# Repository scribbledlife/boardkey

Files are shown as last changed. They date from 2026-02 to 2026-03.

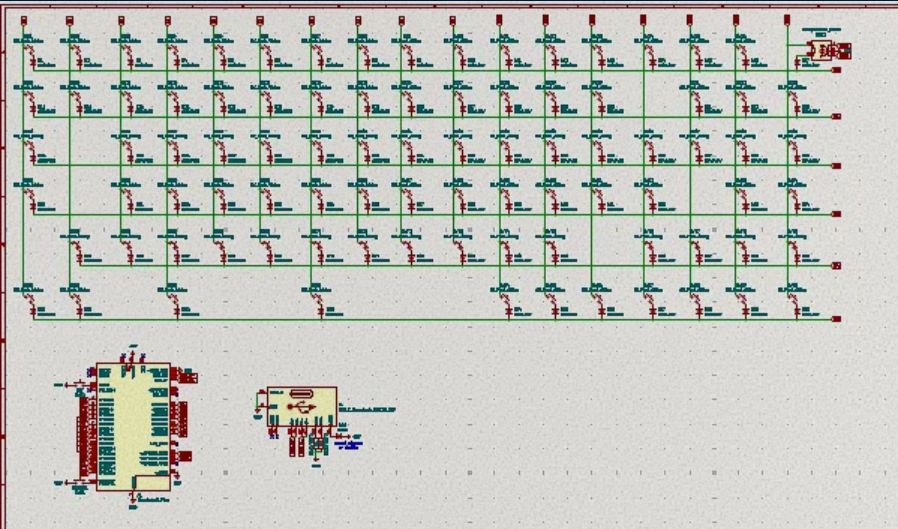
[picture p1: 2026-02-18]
images/boardkey_schematic.png

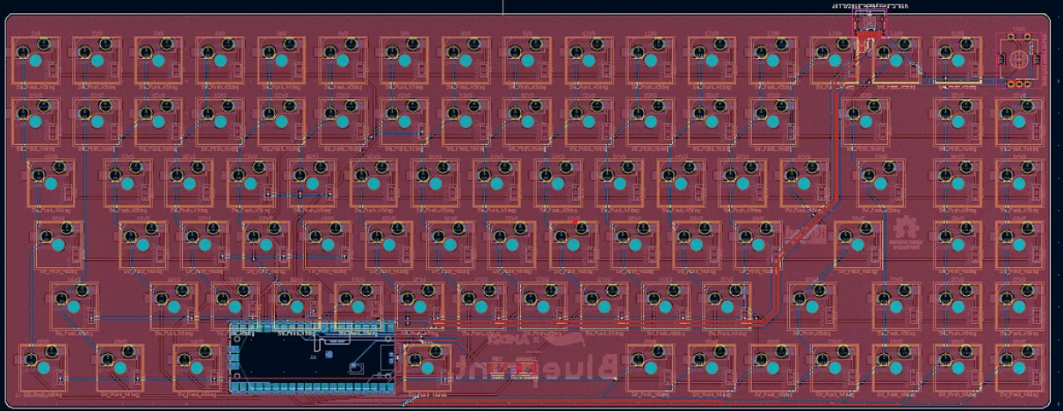
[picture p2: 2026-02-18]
images/boardkey_PCB.png

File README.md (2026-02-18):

# Boardkey

A custom 75% (84+5+1) mechanical keyboard powered by a Raspberry Pi Pico running KMK firmware.

## About

**boardkey** is a compact custom mechanical keyboard with the popular 75% layout extended with extra macro keys and a rotary encoder.

- **Layout**: 75% ANSI  
- **Total keys**: 90 (84 regular + 5 macro + 1 encoder switch)  
- **Microcontroller**: Raspberry Pi Pico  
- **Firmware**: KMK (Python-based, very flexible)

### Key breakdown
- 84 regular ANSI keys  
- 5 programmable macro/layer keys  
- 1 rotary encoder with integrated push switch



## Special Keys & Features

### Media Controls
- **Double tap F1** → Previous track  
- **Double tap F2** → Play / Pause  
- **Double tap F3** → Next track  

### Rotary Encoder
- **Turn left/right** → Volume Down / Volume Up  
- **Press + turn** → Brightness Down / Brightness Up  
- **Double press** → Mute / Unmute  

*(All of these are easily customizable in the `kb.py` / `main.py` KMK keymap file.)*

## Build details (optional sections you can expand)

- Case: 3D Printed, and looks like the following -





- Plate: Looks like this



- Switches: Gateron Milky Yellows
- Keycaps: PBT Keycaps
- Stabilizers: 2u and 6.25u Stabilizers
- PCB:



## Firmware

Firmware is written in CircuitPython using the excellent [KMK](https://github.com/KMKfw/kmk_firmware) framework.

Main features currently implemented:
- Layer switching
- Media keys via tap dance
- Rotary encoder volume & brightness control
- Macro keys (fully programmable)

To flash / edit:
1. Put the Pico into bootloader mode
2. Drag the KMK CircuitPython UF2 onto it
3. Edit `kb.py` and/or `keymaps/default.py`
4. Save → it auto-reloads

## Gallery

For more images, please go to the images folder, and if you want to see the materials, you can go to 

## Thanks / Inspiration

- Huge shoutout to the KMK community
- Linus Tech Tips
- Hack Club Community for the inspiration and help

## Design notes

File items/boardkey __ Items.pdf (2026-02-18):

Qty | Item/Name | Cost (CAD) | URL
89 | Gateron Milky Yellow Switches | $29.73 | Gateron Mily Yellow (https://www.aliexpress.com/item/1005008397216226.html?curPageLogUid=QEhXruD5pt11)
89 | Hotswappable Sockets | $10.02 | Kailhi Hot swappable Sockets (https://www.aliexpress.com/item/1005007639688349.html?mp=1)
90 | 1N4148W SOD-123 Diode | $1.59 | 1N4148W SOD-123 Diode (https://www.aliexpress.com/item/1005007536859190.html?curPageLogUid=dW8W7jVtVMJh)
1 | Rotary Encoder with switch | $1.59 | EC11 Rotary Encoder Code Switch (https://www.aliexpress.com/p/tesla-landing/index.html?scenario=c_ppc_item_bridge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)
3 | 2u Mx Stabilizer | $1.59 | 2u & 6.25U Stabilizer (https://www.aliexpress.com/item/1005004229140548.html?curPageLogUid=2GU49JZQrbhk)
1 | 6.25u Mx Stabilizer | $0 | 2u & 6.25U Stabilizer (https://www.aliexpress.com/item/1005004229140548.html?curPageLogUid=2GU49JZQrbhk)
1 | Keycap Set | $21.32 | PBT Keycaps (https://www.aliexpress.com/item/1005007051744953.html?curPageLogUid=0L05RmxX3qka)
1 | Raspberry Pi Pico (RP2350) | $10.68 | Raspberry Pi Pico RP2350 (https://www.aliexpress.com/item/1005007668131710.html?curPageLogUid=Zf9U3tLoK9uZ)
1 | USB C Socket | $1.38 | USB C Socket SMD (https://www.aliexpress.com/item/1005010588483093.html?curPageLogUid=UxecCxnBFgil)
2 | 5.1k 0402 SMD resistor | $2.07 | 5.1k 0402 SMD resistor (https://www.aliexpress.com/item/1005010725139976.html?curPageLogUid=Wq3j38MQqEIR)
4 | M2 Screw (13.9mm Max) | $1.59 | M2 Screw (12 mm) (https://www.aliexpress.com/item/32969042589.html?curPageLogUid=ekUhYhjyRFyN)
4 | M2 Heatset Female Socket | $1.59 | M2 Heatset Insert (OD3.2mm, 3mm deep) (https://www.aliexpress.com/item/1005010362011631.html?curPageLogUid=dGmJEGkHirNR)
1 | PCB | $29.84 | www.jlcpcb.com
1 | 3D Printed Case | ? | Printing Legion

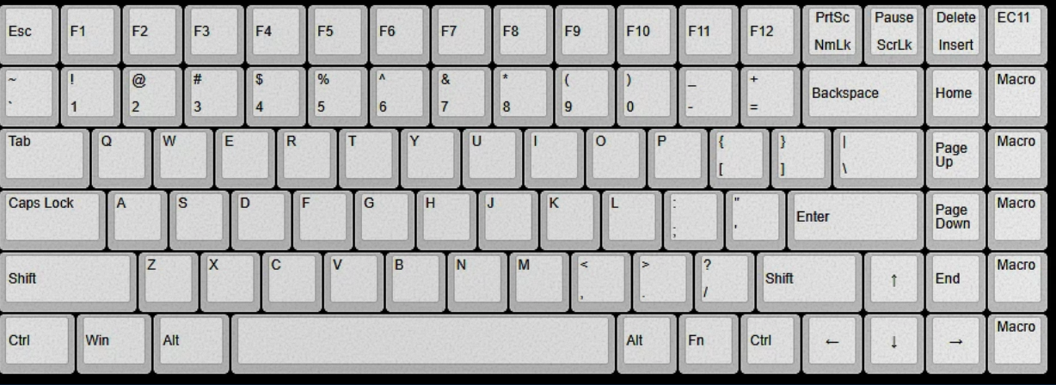
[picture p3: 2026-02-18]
images/boardkey_keyboard_layout.png

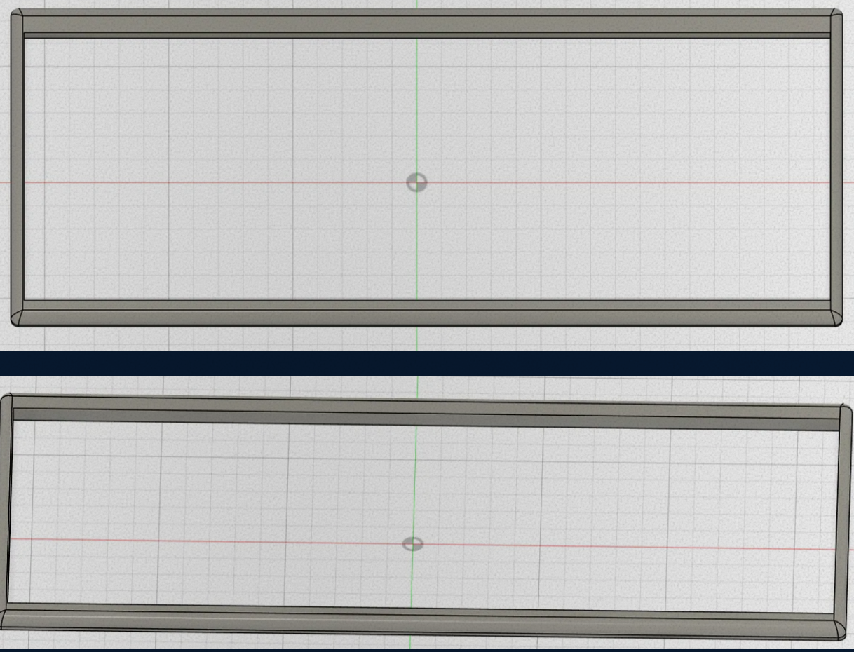
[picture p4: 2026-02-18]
images/boardkey_topcase.png

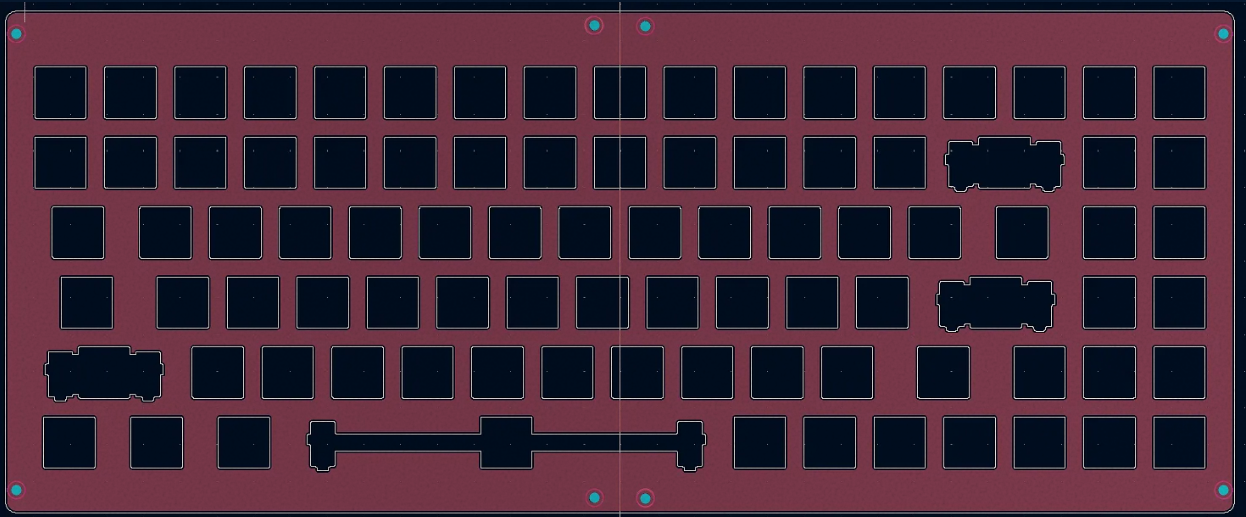
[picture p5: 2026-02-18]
images/boardkey_topplate_PCB.png

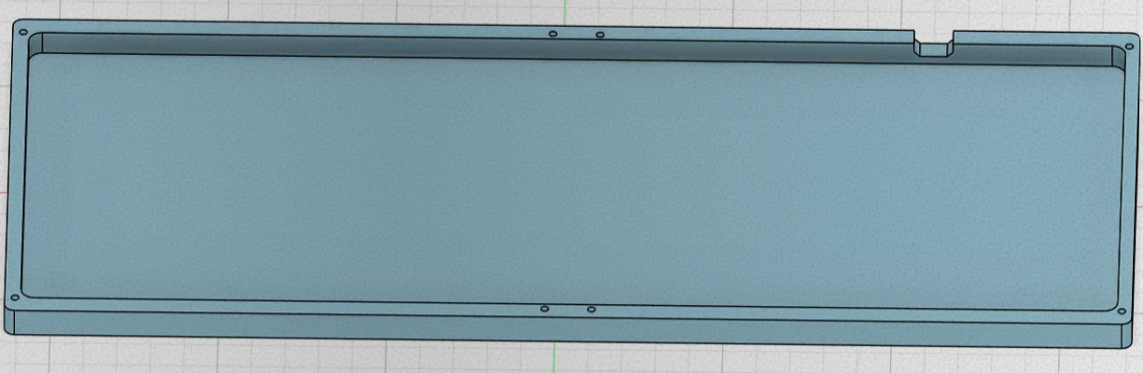
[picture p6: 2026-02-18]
images/boardkey_bottomcase.png

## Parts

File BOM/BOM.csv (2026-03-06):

Qty | Item/Name | Cost (CAD) | Cost (USD) | URL
89 | Gateron Milky Yellow Switches | $29.73 | $21.73 | Gateron Milky Yellow
3 | 2u MX Stabilizer | $1.59 | $1.16 | 2u & 6.25U Stabilizer
1 | 6.25u MX Stabilizer | $0.00 | $0.00 | 2u & 6.25U Stabilizer
1 | Keycap Set (PBT) | $21.32 | $15.59 | PBT Keycaps
1 | Raspberry Pi Pico (RP2350) | $10.68 | $7.81 | Raspberry Pi Pico RP2350
1 | USB C Socket SMD | $1.38 | $1.01 | USB C Socket SMD
2 | 5.1k 0402 SMD Resistor | $2.07 | $1.51 | 5.1k 0402 SMD resistor
4 | M2 Screw (13.9mm Max) | $1.59 | $1.16 | M2 Screw (12 mm)
4 | M2 Heatset Female Socket (OD3.2mm 3mm deep) | $1.59 | $1.16 | M2 Heatset Insert (OD3.2mm 3mm deep)
1 | PCB (JLCPCB) | $29.84 | $21.81 | www.jlcpcb.com
1 | 3D Printed Case | ? | ? | Printing Legion

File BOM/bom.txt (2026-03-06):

For Access to the URLs go to this link: https://docs.google.com/document/d/1M_K4j3Ae2GVynViHfFqDaqfhLQH_BuVz880BT4pgvuY/edit?usp=sharing

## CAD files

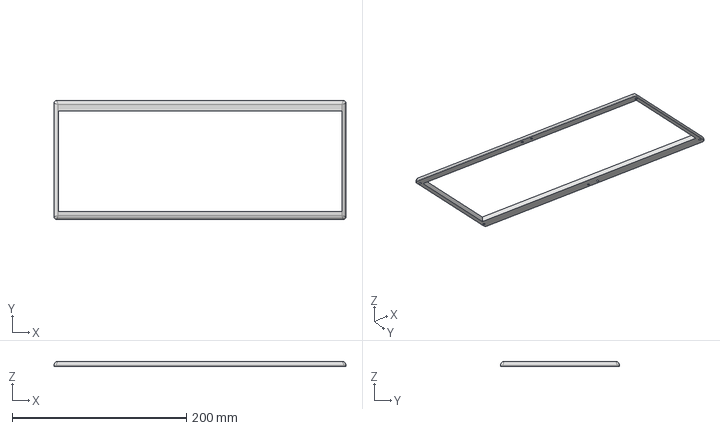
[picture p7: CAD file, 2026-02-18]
case_cad/boardkey_casetop.step
335.1 x 136.5 x 6.30 mm

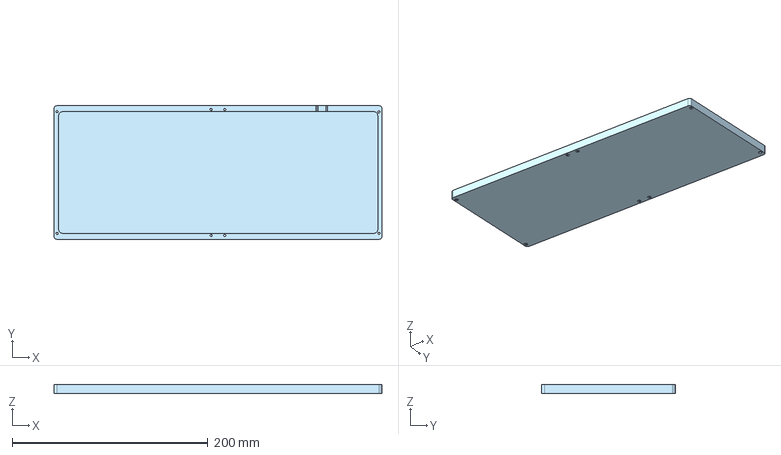
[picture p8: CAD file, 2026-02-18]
case_cad/boardkey_casebottom.step
335.1 x 136.5 x 9.30 mm

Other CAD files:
case_cad/boardkey_casebottom.stl
case_cad/boardkey_casetop.stl

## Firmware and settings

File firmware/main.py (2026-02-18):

import board
# import digitalio
from kmk.kmk_keyboard import KMKKeyboard
from kmk.scanners.keypad import MatrixScanner
from kmk.keys import KC
from kmk.scanners import DiodeOrientation
from kmk.extensions.RGB import RGB, AnimationModes
from kmk.modules.macros import Macros, Press, Release, Tap, Delay
from kmk.modules.mouse_keys import MouseKeys
from kmk.extensions.media_keys import MediaKeys
from kmk.modules.encoder import EncoderHandler
from kmk.modules.layers import Layers
from kmk.modules.tapdance import TapDance

keyboard = KMKKeyboard()
macros = Macros()
keyboard.modules.append(macros)
mouse = MouseKeys()
encoder_handler = EncoderHandler()
tapdance = TapDance()
tapdance.tap_time = 250
keyboard.modules.append(MouseKeys())
keyboard.extensions.append(MediaKeys())
keyboard.modules.append(encoder_handler)
keyboard.modules.append(Layers())
keyboard.modules.append(tapdance)

# R0 - R5
keyboard.row_pins = (board.GP22, board.GP19, board.GP18, board.GP17, board.GP16, board.GP11)
# C0 - C16
keyboard.col_pins = (board.GP12, board.GP13, board.GP14, board.GP15, board.GP20, board.GP21, board.GP2, board.GP1, board.GP0, board.GP3, board.GP4, board.GP5, board.GP6, board.GP7, board.GP8, board.GP9, board.GP10)

keyboard.diode_orientation = DiodeOrientation.COL2ROW

_______ = KC.TRNS
xxxxxxx = KC.NO
xxxx = KC.NO
Fn = KC.MO(1)

RSW = KC.TD(Fn, KC.MUTE)
LOCKTD = KC.TD(KC.NO, KC.MACRO(Press(KC.LGUI), Delay(100), Tap(KC.L), Release(KC.LGUI)))
text = KC.TD(KC.NO, KC.MACRO(custom, Tap(KC.ENTER)))
RMB = KC.TD(KC.MACRO(Release(KC.MB_RMB)), KC.MACRO(Press(KC.MB_RMB)),)

F1 = KC.TD(KC.F1, KC.MPRV)
F2 = KC.TD(KC.F2, KC.MPLY)
F3 = KC.TD(KC.F3, KC.MNXT)

WAVE = KC.MACRO(Tap(KC.DOT), Delay(100), Tap(KC.N1))
GD = KC.MACRO(Tap(KC.E), Tap(KC.T), Tap(KC.Q), Tap(KC.Y), Tap(KC.R))
WAVEGD = KC.TD(WAVE, GD)

FPS = KC.MACRO(Press(KC.LSFT), Delay(100), Tap(KC.F5), Release(KC.LSFT))
PING = KC.MACRO(Press(KC.LCTRL), Press(KC.LSFT), Press(KC.F7), Release(KC.LCTRL), Release(KC.LSFT), Release(KC.F7))
FPSPING = KC.TD(FPS, PING)

keyboard.keymap = [
    # Base (Layer 0)
    [
        KC.ESC,   F1,      F2,    F3,      KC.F4, KC.F5, KC.F6,    KC.F7, KC.F8, KC.F9,    KC.F10,  KC.F11,    KC.F12,   KC.PSCR,  KC.PAUS, KC.DEL,   RSW,
        KC.GRAVE, KC.N1,   KC.N2, KC.N3,   KC.N4, KC.N5, KC.N6,    KC.N7, KC.N8, KC.N9,    KC.N0,   KC.MINUS,  KC.EQUAL, xxxxxxx,  KC.BSPC, KC.HOME,  KC.MUTE,
        KC.TAB,   xxxxxxx, KC.Q,  KC.W,    KC.E,  KC.R,  KC.T,     KC.Y,  KC.U,  KC.I,     KC.O,    KC.P,      KC.LBRC,  KC.RBRC,  KC.BSLS, KC.PGUP,  LOCKTD,
        KC.CAPS,  xxxxxxx, KC.A,  KC.S,    KC.D,  KC.F,  KC.G,     KC.H,  KC.J,  KC.K,     KC.L,    KC.SCOLON, KC.QUOTE, KC.ENTER, KC.NO,   KC.PGDN,  WAVEGD,
        xxxxxxx,  KC.LSFT, KC.Z,  KC.X,    KC.C,  KC.V,  KC.B,     KC.N,  KC.M,  KC.COMMA, KC.DOT,  KC.SLASH,  xxxxxxx,  KC.RSFT,  KC.UP,   KC.END,   FPSPING,
        KC.LCTRL, KC.LGUI, xxxx,  KC.LALT, xxxx,  xxxx,  KC.SPACE, xxxx,  xxxx,  xxxxxxx,  KC.RALT, Fn,        KC.RCTRL, KC.LEFT,  KC.DOWN, KC.RIGHT, xxxxxxx,
    ],
    # Fn (Layer 1)
    [
        xxxxxxx, xxxxxxx, xxxxxxx,  xxxxxxx,  xxxxxxx,  xxxxxxx,   xxxxxxx,  xxxxxxx, xxxxxxx, xxxxxxx, xxxxxxx,  xxxxxxx, xxxxxxx, KC.NLCK, KC.SLCK, KC.INS,  _______,
        _______, _______, _______,  _______,  _______,  _______,   _______,  _______, _______, _______, _______,  _______, _______, _______, _______, _______, _______,
        _______, _______, _______,  KC.MS_UP, _______,  KC.MB_LMB, KC.MW_UP, _______, _______, _______, _______,  _______, _______, _______, _______, _______, _______,
        _______, _______, KC.MS_LT, KC.MS_DN, KC.MS_RT, KC.MB_RMB, KC.MW_DN, _______, _______, _______, _______,  _______, _______, _______, _______, _______, text,
        _______, _______, _______,  _______,  _______,  _______,   _______,  _______, _______, _______, _______,  _______, _______, _______, _______, _______, _______,
        _______, _______, _______,  _______,  _______,  _______,   _______,  _______, _______, _______, _______,  _______, _______, _______, _______, _______, RMB,
    ]
]

# volume knob
encoder_handler.pins = ((board.GP26, board.GP27),)
encoder_handler.map = [
    ((KC.VOLD, KC.VOLU),), # Volume
    ((KC.BRID, KC.BRIU),), # Brightness (Fn)
    ]

# RPi Pico GP25 LED
'''
led = digitalio.DigitalInOut(board.GP25)
led.direction = digitalio.Direction.OUTPUT
led.value = True
'''

if __name__ == '__main__':
    keyboard.go()

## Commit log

2026-02-18 Update and rename kicad/actual_boardkey/PCBboardkey.kicad_pcb to kicad/actual_boardkey/PCB/boardkey.kicad_pcb
    [boardkey.kicad_pcb]
2026-02-18 Update and rename kicad/actual_boardkey/PCB/boardkey.kicad_pcb to kicad/boardkey.kicad_pcb
    [boardkey.kicad_pcb]
2026-02-18 Update and rename kicad/boardkey.kicad_pcb to kicad/acutal_boardkey/boardkey.kicad_pcb
    [boardkey.kicad_pcb]
2026-02-18 Update and rename kicad/acutal_boardkey/boardkey.kicad_pcb to kicad/boardkey.kicad_pcb
    [boardkey.kicad_pcb]
2026-02-18 bunch of files
    [boardkey_switches.kicad_sch, boardkey_top_plate.kicad_pcb]
2026-02-18 Update and rename boardkey_switches.kicad_sch to kicad/boardkey_switches.kicad_sch
    [boardkey_switches.kicad_sch]
2026-02-18 Update and rename boardkey_top_plate.kicad_pcb to kicad/boardkey_top_plate.kicad_pcb
    [boardkey_top_plate.kicad_pcb]
2026-02-18 Update and rename boardkey_casebottom.step to case_cad/boardkey_casebottom.step
    [boardkey_casebottom.step]
2026-02-18 Update and rename boardkey_casetop.step to case_cad/boardkey_casetop.step
    [boardkey_casetop.step]
2026-02-18 Rename boardkey __ Items.pdf to items/boardkey __ Items.pdf
2026-02-20 Update and rename bom.csv to BOM.csv
    [BOM.csv]
